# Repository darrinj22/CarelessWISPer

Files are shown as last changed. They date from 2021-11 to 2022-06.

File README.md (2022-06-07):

# CarelessWISPer 
Wireless Electronic Shopping Label | 
NCSU Senior Capstone Project 2021

## Introduction
CarelessWISPer, named after the famous (infamous?) George Michael song, is an Electronic Shopping Label System. Engineered
to act as an RFID area reader for consumer products, item tracking, and further applications. Using an ePaper Display, and ESP32 microcontroller, and an RFID module, this product has the capability of giving detailed item descriptions of each product on a shelf. 

## How to Browse

- This github repository is split into 3 main sections: Code, Tutorials, and Fabrication Files
- Within the code section, all of the code that was used to make this project work can be found. Note that this requires the installation of either the Arduino IDE (if you use all the code packed into one .ino file), or the Platform.io extension in Visual Studio to utilize the better and more structured codebase.
- The tutorial section contains descriptions on setting up the database using XAMPP, as well as establishing connection between the ESP32 and ePaper Display. 
- The fabrication section will contain all of the gerber files necessary to fabricate the PCB and needed parts for the project. 

## Installation
To use these code files to implement this system. Read the files contained within the Tutorials section. 

## Contact
Contact darrinjhansen@gmail.com for any questions.

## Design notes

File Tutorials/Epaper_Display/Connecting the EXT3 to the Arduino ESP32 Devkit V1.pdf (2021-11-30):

# Connecting the EXT3 to the ESP32 Devkit V1 with Arduino

# Scope

This configuration has been tested successfully against

ESP32 Devkit V1 (https://embeddedcomputing.weebly.com/espressif-platform.html) for the screens up to 2.66"

This configuration may also suit other boards with the Arduino form-factor, with the size of the screen adapted to the available SRAM of the MCU.

# Software

On the main sketch, set the board to boardESP32,

corresponding to the pins defined in the

### hV_Configuration.h file of the

ePaper_EXT3_Basic_Library (link 1, (https://github.com/PervasiveDisplays/PDLS_EXT3_Basic) link 2). (https://github.com/rei-vilo/PDLS_EXT3_Basic)

# Notes

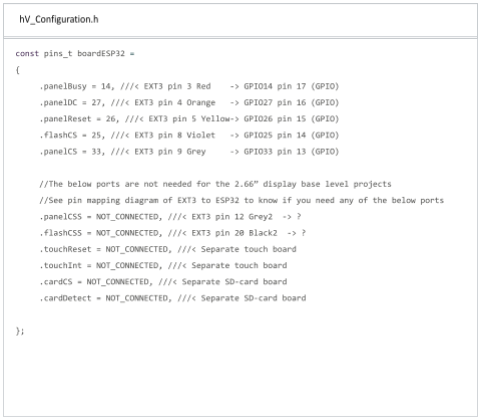
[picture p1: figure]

There are multiple releases of the ESP32 (https://embeddedcomputing.weebly.com/espressif-platform.html) with slight incompatibilities. In this we are using the ESP32 Devkit V1. Setup the ESP32 library in Arduino IDE by following the steps found here. (https://randomnerdtutorials.com/installing-the-esp32-board-in-arduino-ide-windows-instructions/)

After downloading the code from the above-mentioned github repository, there are a couple of things that need to be completed before flashing the project to ESP32. First, open up hV.Configuration, and declare the board that will be used, in our case, boardESP32. We have configured this specific pin mapping (remember, the pin number reflects the GPIO pin and not necessarily the physical pin number) so that it is compatible with the example projects in the ePaper_EXT_3_Basic_Library. If the GPIO pins we have mapped conflict with your project specifications, adjust accordingly (See Figure 3 Hardware). Next, whatever example.ino file you decide to use from ePaper_EXT3_Basic_Library, you will need to declare your board in the example.ino file as seen in the Sketch.ino image above. Make sure all other declarations are commented out except for the screen that you will be using. For our 2.66” display, we have selected the declaration with eScreen_EPD_EXT3_266 input. Finally, connect the EXT3 board to ESP32 (See Figure 2 Hardware), flash the selected example.ino project onto your ESP32 from Arduino IDE and make sure the image showing on your display matches the example description.

Issue: Some ESP32 will not flash in the Arduino environment. This happened in this example. The work around is to install a 10uf electrolytic capacitor to make the ESP32 automatically go into boot/flash mode (See Figure 1 in Hardware). After configuring the circuit either by soldering the capacitor to the board, or using a breadboard as seen in the figure below, ESP32 should be able to successfully flash code through Arduino IDE.

# Hardware

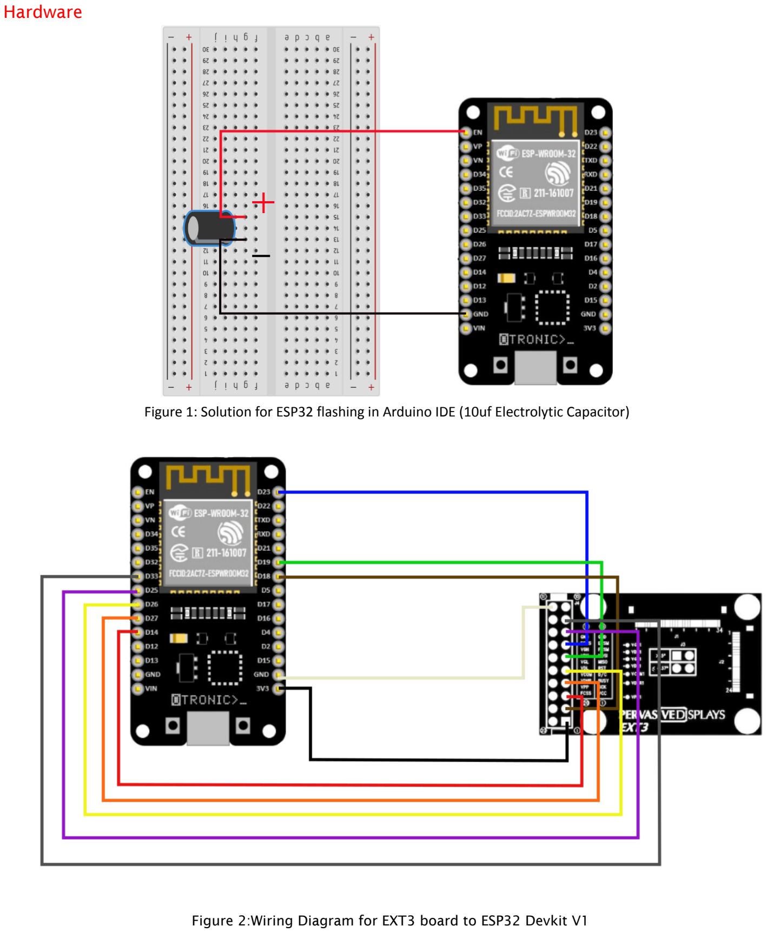
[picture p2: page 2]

## Figure 1: Solution for ESP32 flashing in Arduino IDE (10uf Electrolytic Capacitor)

## Figure 2:Wiring Diagram for EXT3 board to ESP32 Devkit V1

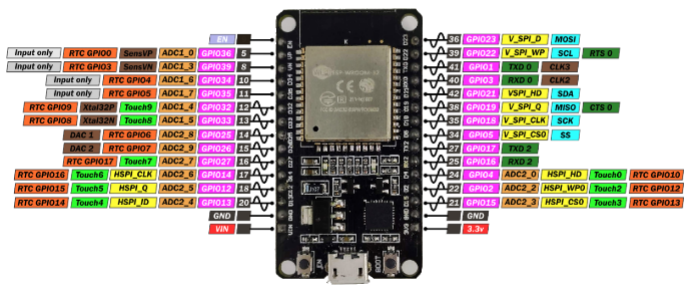
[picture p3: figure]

## Figure 3: ESP32 Devkit V1 Pinout

# Options

Large screens 9.7" and 12.2" require panelCSS to be defined and connected.

If the second memory is populated on the EXT3 board, lashCSS needs to be defined and connected. The library will keep lashCSS HIGH to avoid any interferences with the other

devices connected to the SPI bus.

ESP32 Image: https://www.otronic.nl/a-59613972/esp32/esp32-wroom-4mb-devkit-v1-board-met-wifi-bluetooth-en-dual-core-processor/ , Otronic

Pervasive Display EXT3 Image:https://embeddedcomputing.weebly.com/connecting-the-e-paper-epd-extension-kit-gen-3.html. , REI VILO

ESP32 Pinout Image: https://www.mischianti.org/wp-content/uploads/2020/11/ESP32-DOIT-DEV-KIT-v1-pinout-mischianti.png , RENZO MISCHIANTI (https://www.mischianti.org/author/reef/)

Created 10/12/2021 W. Shepherd Pitts, PhD, NCSU
Modified 10/12/2021 Joe Harrison, NCSU

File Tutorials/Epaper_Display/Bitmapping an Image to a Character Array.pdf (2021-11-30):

## Bitmapping a BMP/PNG Image to a Character Array and Displaying the Image on Pervasive Display's - 2.66" E ink Display - Aurora -25(V430)

## Scope

This configuration has been tested successfully against

ESP32 Devkit V1 (https://embeddedcomputing.weebly.com/espressif-platform.html) for the screens up to 2.66”

This configuration may also suit other boards with the Arduino form-factor, with the size of the screen adapted to the available SRAM of the MCU.

## Software

If not already done, follow the instructions ***HERE*** (https://docs.google.com/document/u/1/d/1n4Jl7uKD6odnbmRgLsNShRXBoZbzR4CFlCR1YncSQME/edit) to get the correct setup required to display an image on the 2.66” E ink display from Pervasive Display.

## Notes

After having completed the setup from the linked document in the Software section, you should be able to display the images found in the example.ino files in Arduino IDE. Next, we will now configure our project to be able to display custom images through bit mapping images to C/C++ character arrays.

Step 1:
Download the github repository located here. After downloading the files, open up the EPD_sub_5_inch.ino file. Start off by declaring your board much like in the guide for connecting the EXT3 board. Also you will need to correctly declare valid pins for your board. (See below) Then run the program to make sure that the project is flashing correctly to ESP32.
The program should display an image for around 5 seconds, and then display a second image.

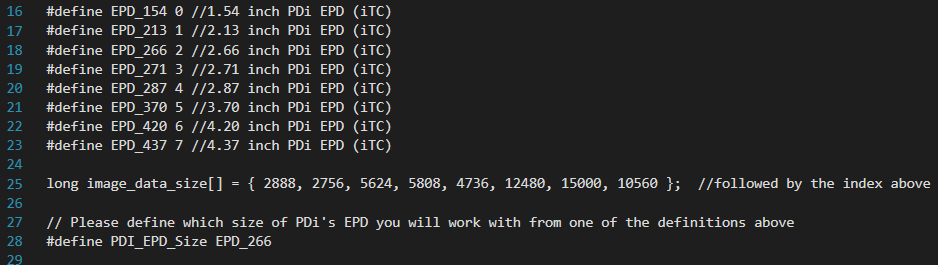
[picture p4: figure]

For the code below, you will have to make sure that the pins are aligned correctly with the configuration that you are using for your specific project.

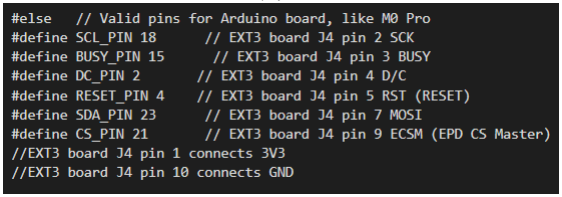
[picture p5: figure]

Next, locate this chunk of code:

Step 2:
Directly underneath this code, delete/comment out the following lines. #include "image_data\2.66\image_266_296x152_BWR.c"
#define BWR_blackBuffer | (uint8_t *) & image_266_296x152_BWR_blackBuffer

#define BWR_redBuffer | (uint8_t *) & image_266_296x152_BWR_redBuffer

So now your code should look like this:

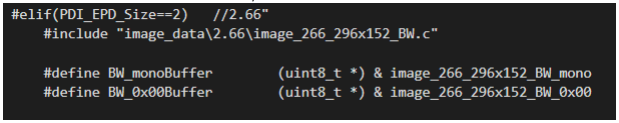
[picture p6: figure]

Step 3:
Next, open up the file in the directory above, image_266_296x152_BW.c This is the file that contains the arrays for whichever image you are going to be displaying on your screen. First, delete the code that sends the second image:

// Send 2nd image data for black, white and red colors
sendIndexData( 0x10, BWR_blackBuffer, image_data_size[PDI_EPD_Size] ); //First frame: black frame where 1=black and 0=white or color pixel sendIndexData( 0x13, BWR_redBuffer, image_data_size[PDI_EPD_Size] ); //Second frame: color frame where 1=color and 0=white or black pixel sendIndexData( 0x12, &register_data[0], 1 ); //Display Refresh
while( digitalRead( BUSY_PIN ) != HIGH );

This will make it easier for debugging because you will only be focused on being able to Send one image to your board. Once you can correctly send a desired image to your board, you can go back and add the code to send multiple images to the board.

Step 4:
Within the image_266_296x152_BW.c file, delete all the characters within the image_266_296x152_BW_mono array, but do not delete the array declaration, because once we correctly bitmap an image, we will paste the converted image into the array declaration. Now, we will take a black and white image of your choice to be updated on the display. I used the image found here. (https://raw.githubusercontent.com/PervasiveDisplays/ePaper_EXT3_DrivingCode/main/EPD_sub_5_inch/images/2.66/266_296x152_BW.bmp) Since we already have the array for this image, we will open this image up in an editor (Photoshop,Gimp,etc.) and change the image to your liking. Then, rotate the image within the editor so that it has this orientation

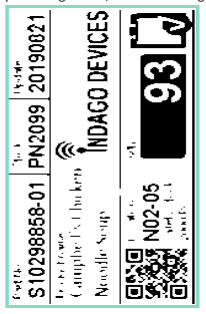
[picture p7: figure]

Save the image as a .bmp or .png file. Depending on the photo editor that you are using, one of these types of files will be needed for the next step. While doing the next step, If the .bmp does not work, try it with the .png instead, and vice versa.

Step 5:
Open up the website found here. (https://javl.github.io/image2cpp/) Select the image that you edited in the previous step and upload it to the application. Within the image settings, make sure you have the canvas size set appropriately(for the 2.66” display, 152x296). Also you will most likely need to invert the image colors. You should now see your image in the preview like this

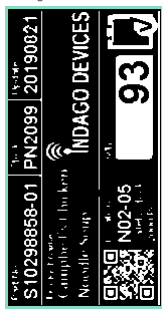
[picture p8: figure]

Next, go the output portion of the application and make sure that output format is set to Arduino Code, and the Draw mode is set To Horizontal - 1 bit per pixel. Now generate the code. Take the array that was generated and paste it into the array that we talked about in step 4.

Step 6:
After saving the array, now run the EPD_sub_5_inch.ino program and the display should be outputting the image that you created within your editor.

## Desired Outcome

Here, (https://drive.google.com/file/d/11dbviFQ2u1dpbYEQ8GaudZTZPbHVXqvW/view?usp=sharing) you will see a basic program that runs through 4 images.

To get over the air flashing of your ESP32, follow the guide found here. (https://lastminuteengineers.com/esp32-ota-web-updater-arduino-ide/)

Lastly, here are some useful links concerning the ESP32/Epaper display. (https://docs.google.com/document/d/1-DGhHi2krR2uHqgw9-P19peYgrpZNnmpY0OJPN4OhO0/edit)

## Options

Large screens 9.7" and 12.2" require panelCSS to be defined and connected.

If the second memory is populated on the EXT3 board, lashCSS needs to be defined and

connected. The library will keep lashCSS HIGH to avoid any interferences with the other

devices connected to the SPI bus.

Created 10/12/2021 Joe Harrison, NCSU

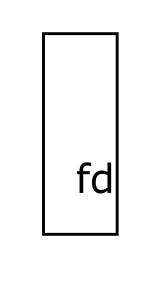
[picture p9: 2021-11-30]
bitmap1.png

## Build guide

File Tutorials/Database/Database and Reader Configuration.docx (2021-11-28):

Database and Reader Configuration

The goal of this document is to detail the storage of data collected from the reader. For the purposes of this project, only the EPC codes were scanned and captured, but all data from tags such as the wisp could be collected and stored in a similar fashion. The flow chart below describes the process:

Reader gets tag info → ESP32 collects the data → HTTP Request to Web Server → PHP Script → MySQL

We’re going to assume we already have the data that we need to input and begin the setup of the actual database.

Database Configuration

1. Download XAMPP. https://www.apachefriends.org/download.html

XAMPP is an open-source web server stack that stands for Apache HTTP server, MariaDB (MySQL) database, PHP, and Perl. We are going to use XAMPP as a local server to host our information.

2. Once downloaded, open XAMPP and start both the Apache and MySQL Modules, the other three aren’t used.
3. Open the Shell on the XAMPP control panel.
4. Login once using the root username and password by using the following in the shell:
  a. mysql.exe -u root -p
  b. You will then be prompted to enter a password, the password for the root account is: “your-root-password”
5. Now we are going to create a user account that we will use to access the database. The username is CarelessWISPer and the password is shep_123. These can be set to anything when first created. Type the following in the shell:
  a. CREATE USER ‘CarelessWISPer’@’localhost’ IDENTIFIED BY ‘shep_123’;

GRANT ALL PRIVILEGES ON *.* TO ‘CarelessWISPer’@’localhost’ WITH GRANT OPTION;

FLUSH PRIVILEGES;

6. To login to our newly created account, quit the MariaDB editor and reopen, then type:
  a. Mysql.exe -u CarelessWISPer -p
  b. Use ‘shep_123’ as the password.
7. Since we will be storing the epc values from the tags, we will create a database and table to store them. First, create a database called db_epc by entering the following into the shell:
  a. CREATE DATABASE db_epc CHARACTER SET = ‘utf8’ COLLATE=’utf8_general_ci’;
8. Now, create a table within the database that will actually store the information. First set which database we will be working in:
  a. USE db_epc;
9. Then, create the table named epc_vals ( the name doesn’t matter as long as everything is consistent across the ESP32 code, PHP script and MySQL Server).

CREATE TABLE epc_vals(

tag_id INT UNSIGNED NOT NULL AUTO_INCREMENT,

product_name VARCHAR(40),

tag_epc VARCHAR(36),

last_edited TIMESTAMP(6) NOT NULL DEFAULT CURRENT_TIMESTAMP(6) ON UPDATE CURRENT_TIMESTAMP(6),

tag_state VARCHAR(30),

entry_date DATETIME(6),

PRIMARY KEY (tag_id));

10. Now that we have a place to store our values, we can look into actually inserting them by writing a php script. Open a text editor and paste the following code, there should also be a php file included in the folder where this document was found that contains this code.

<?php

if(isset($_GET["epc"])) {

$epc = $_GET["epc"];

$servername = "localhost";

$username = "CarelessWISPer";

$password = "shep_123";

$dbname = "db_epc";

$timeout = "20";

// Create connection

$conn = new mysqli($servername, $username, $password, $dbname);

// Check connection

if ($conn->connect_error) {

die("Connection failed: " . $conn->connect_error);

}

$sql = "CALL insert_data($epc,$timeout)";

if ($conn->query($sql) === TRUE) {

echo "New record created successfully";

} else {

echo "Error: " . $sql . " => " . $conn->error;

}

$conn->close();

} else {

echo "epc is not set";

}

?>

Save the code from above as a .php file and make sure that it is in the following directory:

a. C:\xampp\htdocs
11. One thing to note is that in the php file, there is a line that reads:
  a. $sql = “CALL insert_data($epc,$timeout)”;

This is a call to a stored procedure in the database, you will need to make this function in order to make sure this works properly, to do so, paste the following code into the MySQL shell:

DELIMITER //

CREATE PROCEDURE insert_data(parameter_tag_epc VARCHAR(36), parameter_timeout INTEGER)

MODIFIES SQL DATA

BEGIN

INSERT INTO epc_vals (tag_epc,entry_date,tag_state) VALUES (parameter_tag_epc,NOW(),'Recent Batch');

DELETE FROM epc_vals WHERE entry_date < NOW() - INTERVAL parameter_timeout MINUTE;

UPDATE epc_vals SET tag_state = 'Old Batch' WHERE entry_date < NOW() - INTERVAL 70 SECOND;

UPDATE epc_vals SET product_name = 'CHEEZIT' WHERE LEFT(tag_epc,11) = '22600295125';

UPDATE epc_vals SET product_name = 'MT DEW' WHERE LEFT(tag_epc,11) = '16026516616';

CREATE OR REPLACE TABLE product_info SELECT product_name, tag_epc,entry_date, COUNT(*) times_item_was_seen FROM epc_vals GROUP BY tag_epc ORDER BY entry_date DESC;

END;//

DELIMITER ;

A few things to note, specifically with the lines marked yellow. These are only used as a way to distinguish between our specific tags and organize the data we had, they are not necessary to the functionality of the database.

12. Then, create an Arduino Sketch and place the following code into three separate files. Make sure to change the wifi and server settings to your appropriate settings.

Main Code:

/*

Epaper Display Scan for Gen2 EPC Values and Update Database

Authors: DJ Hansen, Joe Harrison, Jon Mark Long, Daniel Higgins

Date: November 29th, 2021

About: Electronic Wireless Shopping Label System code including Gen 2 Reader, MySQL Database Connection, and

Wireless Updating of EPaper Display

*/

/*

*********************************************************************************************************************************

* Preproccesor Directives, MACROS, and header files *

*********************************************************************************************************************************

*/

// processor predirectives and MACROS

#define use_soft_serial 0 // predirective to control whether using software or hardware serial port, if set to 1, then switch on M6E needs to be set to SW

#define DEBUG 0 // 0 : no messages 1 : request sending and receiving

#define EPC_COUNT 20 // how many tags are expected in the area, can reasonably go up to around 100

#define NANOREGION REGION_NORTHAMERICA //which region the reader operates in, check https://github.com/sparkfun/Simultaneous_RFID_Tag_Reader for other regions

#define ALWAYS 1

// Reader header files

#include "SparkFun_UHF_RFID_Reader.h" //Library for controlling the M6E Nano module

#if use_soft_serial

#include <SoftwareSerial.h> //Used for transmitting to the device

SoftwareSerial softSerial(2, 3); //RX, TX

#else

#define NanoSerial Serial // define the serial port to use (E.g. softSerial, Serial1 etc)

#endif

// Database header files

#include <WiFi.h>

#include <HTTPClient.h>

// ePaper header files

#include <WiFiClient.h>

#include <WebServer.h>

#include <ESPmDNS.h>

#include <Update.h>

#include <SPI.h>

/****************************************************************************************************************************

* Global Variables and Objects needed for Reader and Database Functionality *

****************************************************************************************************************************

*/

uint8_t EPC_recv[EPC_COUNT][12]; //stores unique tag values in a session

const unsigned long time_pd_wait = 60000; // how long we should wait in between scan sessions (ms)

const unsigned long time_pd_scan = 30000; // scan duration (ms)

unsigned long prev_time = 0; // timer wait update

unsigned long prev_scan_time = 0; // timer scan update

bool onetime = true; // one time flag

bool firstTime = true; // one time flag

unsigned long scan_time = 0; // used to store millis()

const char WIFI_SSID[] = "ncsu"; // wifi network name

const char WIFI_PASSWORD[] = ""; // wifi password

String HOST_NAME = "http://10.155.25.216:80"; // PC's IP address, use port 80

String PATH_NAME = "/insert_epc.php"; // php file placed in C:\xampp\htdocs

String queryString; // query to send to database

String final_epc[EPC_COUNT]; // string epc values

const unsigned long update_db = 30000; //database update time (ms)

unsigned long prev_time_db = 0; // timer update

uint8_t first_flag = 0; // one time flag

int httpCode; // stores code from http connection attempt

String payload; //

// Object Instances

RFID nano; //Create instance for reader

HTTPClient http; //Create instance for http connection

/*

*

* **********************************************************************************************************************

* Everything from this point until line 365 is used for Updating and Flashing an image onto the Epaper Display *

* **********************************************************************************************************************

*/

bool add_image_done = false;

const char* host = "esp32";

const char* ssid = "ncsu";

const char* password = "";

#define EPD_154 0 //1.54 inch PDi EPD (iTC)

#define EPD_213 1 //2.13 inch PDi EPD (iTC)

#define EPD_266 2 //2.66 inch PDi EPD (iTC)

#define EPD_271 3 //2.71 inch PDi EPD (iTC)

#define EPD_287 4 //2.87 inch PDi EPD (iTC)

#define EPD_370 5 //3.70 inch PDi EPD (iTC)

#define EPD_420 6 //4.20 inch PDi EPD (iTC)

#define EPD_437 7 //4.37 inch PDi EPD (iTC)

long image_data_size[] = { 2888, 2756, 5624, 5808, 4736, 12480, 15000, 10560 }; //followed by the index above

#define PDI_EPD_Size EPD_266

#if (PDI_EPD_Size >= 5) //3.70", 4.20", 4.37"

uint8_t register_data[] = { 0x00, 0x0e, 0x19, 0x02, 0x0f, 0x89 }; //0x00, soft-reset, temperature, active temp., PSR0, PSR1

#else //other small sizes

uint8_t register_data[] = { 0x00, 0x0e, 0x19, 0x02, 0xcf, 0x8d };

#endif

#if(PDI_EPD_Size==2)//2.66"

#include "image_266_296x152_BW.c"

#define BW_monoBuffer (uint8_t *) & image_266_296x152_BW_monoTest

#define BW_monoBuffer1 (uint8_t *) & image_266_296x152_BW_mono1

#define BW_monoBuffer2 (uint8_t *) & image_266_296x152_BW_mono2

#define BW_monoBuffer3 (uint8_t *) & image_266_296x152_BW_mono3

#define BW_monoBuffer4 (uint8_t *) & image_266_296x152_BW_mono4

#define BW_0x00Buffer (uint8_t *) & image_266_296x152_BW_0x00

#elif(PDI_EPD_Size==3) //2.71"

#include "image_data\2.71\image_271_264x176_BW.c"

#include "image_data\2.71\image_271_264x176_BWR.c"

#define BW_monoBuffer (uint8_t *) & image_271_264x176_BW_mono

#define BW_0x00Buffer (uint8_t *) & image_271_264x176_BW_0x00

#define BWR_blackBuffer (uint8_t *) & image_271_264x176_BWR_blackBuffer

#define BWR_redBuffer (uint8_t *) & image_271_264x176_BWR_redBuffer

#endif

#if defined(ENERGIA) // Valid pins for LaunchPad on Energia

#define SCL_PIN 7 // EXT3 board J4 pin 2 SCK

#define BUSY_PIN 11 // EXT3 board J4 pin 3 BUSY

#define DC_PIN 12 // EXT3 board J4 pin 4 D/C

#define RESET_PIN 13 // EXT3 board J4 pin 5 RST (RESET)

#define SDA_PIN 15 // EXT3 board J4 pin 7 MOSI

#define CS_PIN 19 // EXT3 board J4 pin 9 ECSM (EPD CS Master)

// SPI protocl setup

void sendIndexData( uint8_t index, const uint8_t *data, uint32_t len ) {

SPI.begin ();

SPI.setDataMode(SPI_MODE3);

SPI.setClockDivider(SPI_CLOCK_DIV32);

SPI.setBitOrder(MSBFIRST);

digitalWrite( DC_PIN, LOW ); //DC Low

digitalWrite( CS_PIN, LOW ); //CS Low

delayMicroseconds(500);

SPI.transfer( index );

delayMicroseconds(500);

digitalWrite( CS_PIN, HIGH ); //CS High

digitalWrite( DC_PIN, HIGH ); //DC High

digitalWrite( CS_PIN, LOW ); //CS Low

delayMicroseconds(500);

for ( int i = 0; i < len; i++ ) SPI.transfer( data[ i ] );

delayMicroseconds(500);

digitalWrite( CS_PIN, HIGH ); //CS High

}

#else // Valid pins for Arduino board, like M0 Pro

#define SCL_PIN 18 // EXT3 board J4 pin 2 SCK

#define BUSY_PIN 15 // EXT3 board J4 pin 3 BUSY

#define DC_PIN 2 // EXT3 board J4 pin 4 D/C

#define RESET_PIN 4 // EXT3 board J4 pin 5 RST (RESET)

#define SDA_PIN 23 // EXT3 board J4 pin 7 MOSI

#define CS_PIN 21 // EXT3 board J4 pin 9 ECSM (EPD CS Master)

// Software SPI setup

void softwareSpi( uint8_t data ) {

for ( int i = 0; i < 8; i++ ) {

if ((( data >> (7 - i) ) & 0x01 ) == 1 ) digitalWrite( SDA_PIN, HIGH );

else digitalWrite( SDA_PIN, LOW );

digitalWrite( SCL_PIN, HIGH );

digitalWrite( SCL_PIN, LOW );

}

}

// Software SPI protocl setup

void sendIndexData( uint8_t index, const uint8_t *data, uint32_t len ) {

digitalWrite( DC_PIN, LOW ); //DC Low

digitalWrite( CS_PIN, LOW ); //CS Low

softwareSpi( index );

digitalWrite( CS_PIN, HIGH ); //CS High

digitalWrite( DC_PIN, HIGH ); //DC High

digitalWrite( CS_PIN, LOW ); //CS High

for ( int i = 0; i < len; i++ ) softwareSpi( data[ i ] );

digitalWrite( CS_PIN, HIGH ); //CS High

}

#endif

//variabls for blinking an LED with Millis

const int led = 2; // ESP32 Pin to which onboard LED is connected

unsigned long previousMillis = 0; // will store last time LED was updated

const long interval = 1000; // interval at which to blink (milliseconds)

int ledState = LOW; // ledState used to set the LED

WebServer server(80);

/*

* Login page

*/

const char* loginIndex =

"<form name='loginForm'>"

"<table width='20%' bgcolor='A09F9F' align='center'>"

"<tr>"

"<td colspan=2>"

"<center><font size=4><b>ESP32 Login Page</b></font></center>"

"<br>"

"</td>"

"<br>"

"<br>"

"</tr>"

"<tr>"

"<td>Username:</td>"

"<td><input type='text' size=25 name='userid'><br></td>"

"</tr>"

"<br>"

"<br>"

"<tr>"

"<td>Password:</td>"

"<td><input type='Password' size=25 name='pwd'><br></td>"

"<br>"

"<br>"

"</tr>"

"<tr>"

"<td><input type='submit' onclick='check(this.form)' value='Login'></td>"

"</tr>"

"</table>"

"</form>"

"<script>"

"function check(form)"

"{"

"if(form.userid.value=='admin' && form.pwd.value=='admin')"

"{"

"window.open('/serverIndex')"

"}"

"else"

"{"

" alert('Error Password or Username')/*displays error message*/"

"}"

"}"

"</script>";

/*

* Server Index Page

*/

const char* serverIndex =

"<script src='https://ajax.googleapis.com/ajax/libs/jquery/3.2.1/jquery.min.js'></script>"

"<form method='POST' action='#' enctype='multipart/form-data' id='upload_form'>"

"<input type='file' name='update'>"

"<input type='submit' value='Update'>"

"</form>"

"<div id='prg'>progress: 0%</div>"

"<script>"

"$('form').submit(function(e){"

"e.preventDefault();"

"var form = $('#upload_form')[0];"

"var data = new FormData(form);"

" $.ajax({"

"url: '/update',"

"type: 'POST',"

"data: data,"

"contentType: false,"

"processData:false,"

"xhr: function() {"

"var xhr = new window.XMLHttpRequest();"

"xhr.upload.addEventListener('progress', function(evt) {"

"if (evt.lengthComputable) {"

"var per = evt.loaded / evt.total;"

"$('#prg').html('progress: ' + Math.round(per*100) + '%');"

"}"

"}, false);"

"return xhr;"

"},"

"success:function(d, s) {"

"console.log('success!')"

"},"

"error: function (a, b, c) {"

"}"

"});"

"});"

"</script>";

void add_image(void){

pinMode( SCL_PIN, OUTPUT );

pinMode( SDA_PIN, OUTPUT );

pinMode( CS_PIN, OUTPUT );

pinMode( DC_PIN, OUTPUT );

pinMode( RESET_PIN, OUTPUT );

pinMode( BUSY_PIN, INPUT ); //All Pins 0

delay( 5 );

digitalWrite( RESET_PIN, HIGH ); //RES# = 1

delay( 5 );

digitalWrite( RESET_PIN, LOW );

delay( 10 );

digitalWrite( RESET_PIN, HIGH );

delay( 5 );

digitalWrite( CS_PIN, HIGH ); //CS# = 1

sendIndexData( 0x00, &register_data[1], 1 ); //Soft-reset

while( digitalRead( BUSY_PIN ) != HIGH );

sendIndexData( 0xe5, &register_data[2], 1 ); //Input Temperature: 25C

sendIndexData( 0xe0, &register_data[3], 1 ); //Active Temperature

sendIndexData( 0x00, &register_data[4], 2 ); //PSR

// Send 1st image data for black and white colors

sendIndexData( 0x10, BW_monoBuffer1, image_data_size[PDI_EPD_Size] ); //First frame: black frame where 1=black and 0=white pixel

sendIndexData( 0x13, BW_0x00Buffer, image_data_size[PDI_EPD_Size] ); //Second frame: all 0x00

sendIndexData( 0x04, &register_data[0], 1 ); //Power on

while( digitalRead( BUSY_PIN ) != HIGH );

sendIndexData( 0x12, &register_data[0], 1 ); //Display Refresh

while( digitalRead( BUSY_PIN ) != HIGH );

delay( 5000 );

// Send 2nd image data for black and white colors

sendIndexData( 0x10, BW_monoBuffer2, image_data_size[PDI_EPD_Size] ); //First frame: black frame where 1=black and 0=white pixel

sendIndexData( 0x13, BW_0x00Buffer, image_data_size[PDI_EPD_Size] ); //Second frame: all 0x00

sendIndexData( 0x04, &register_data[0], 1 ); //Power on

while( digitalRead( BUSY_PIN ) != HIGH );

sendIndexData( 0x12, &register_data[0], 1 ); //Display Refresh

while( digitalRead( BUSY_PIN ) != HIGH );

delay( 5000 );

// Send 3rd image data for black and white colors

sendIndexData( 0x10, BW_monoBuffer3, image_data_size[PDI_EPD_Size] ); //First frame: black frame where 1=black and 0=white pixel

sendIndexData( 0x13, BW_0x00Buffer, image_data_size[PDI_EPD_Size] ); //Second frame: all 0x00

sendIndexData( 0x04, &register_data[0], 1 ); //Power on

while( digitalRead( BUSY_PIN ) != HIGH );

sendIndexData( 0x12, &register_data[0], 1 ); //Display Refresh

while( digitalRead( BUSY_PIN ) != HIGH );

delay( 5000 );

//Turn-off DC/DC

sendIndexData( 0x02, &register_data[0], 1 ); //Turn off DC/DC

while( digitalRead( BUSY_PIN ) != HIGH );

digitalWrite( DC_PIN, LOW );

digitalWrite( CS_PIN, LOW );

digitalWrite( SDA_PIN, LOW );

digitalWrite( SCL_PIN, LOW );

digitalWrite( BUSY_PIN, LOW );

delay( 150 );

digitalWrite( RESET_PIN, LOW );

}

// End Joe stuff

/*

* ******************************************************************************************************************************

* Function: Setup

* Author: DJ Hansen, Joe Harrison, Jon Mark Long, Daniel Higgins

* Date: 11/29/2021

* About:

* Runs once before going into the Always loop.

* Sets up WiFi, Server, and Serial Connections

* ******************************************************************************************************************************

*/

void setup()

{

Serial.begin(115200);

// Connect to WiFi network

WiFi.begin(ssid, password);

Serial.println("");

// Wait for connection

while (WiFi.status() != WL_CONNECTED) {

delay(500);

Serial.print(".");

}

Serial.println("");

Serial.print("Connected to ");

Serial.println(ssid);

Serial.print("IP address: ");

Serial.println(WiFi.localIP());

/******************************************************************************************************************************/

// Begin Server Connection Setup for EPaper Display

/*use mdns for host name resolution*/

if (!MDNS.begin(host)) { //http://esp32.local

Serial.println("Error setting up MDNS responder!");

while (1) {

delay(1000);

}

}

Serial.println("mDNS responder started");

/*return index page which is stored in serverIndex */

server.on("/", HTTP_GET, []() {

server.sendHeader("Connection", "close");

server.send(200, "text/html", loginIndex);

});

server.on("/serverIndex", HTTP_GET, []() {

server.sendHeader("Connection", "close");

server.send(200, "text/html", serverIndex);

});

/*handling uploading firmware file */

server.on("/update", HTTP_POST, []() {

server.sendHeader("Connection", "close");

server.send(200, "text/plain", (Update.hasError()) ? "FAIL" : "OK");

ESP.restart();

}, []() {

HTTPUpload& upload = server.upload();

if (upload.status == UPLOAD_FILE_START) {

Serial.printf("Update: %s\n", upload.filename.c_str());

if (!Update.begin(UPDATE_SIZE_UNKNOWN)) { //start with max available size

Update.printError(Serial);

}

} else if (upload.status == UPLOAD_FILE_WRITE) {

/* flashing firmware to ESP*/

if (Update.write(upload.buf, upload.currentSize) != upload.currentSize) {

Update.printError(Serial);

}

} else if (upload.status == UPLOAD_FILE_END) {

if (Update.end(true)) { //true to set the size to the current progress

Serial.printf("Update Success: %u\nRebooting...\n", upload.totalSize);

} else {

Update.printError(Serial);

}

}

});

server.begin();

// End Server Connection Setup for EPaper Display

/******************************************************************************************************************************/

// Begin Reader Setup

init_array(); // initializes storage values of EPC to all 0

Serial.begin(115200); // defined elsewhere, can probably remove

while (!Serial); //Wait for the serial port to come online

Serial.println(F("Ready to Begin Program")); //If this prints, then no wiring issues found

if (DEBUG) nano.enableDebugging(Serial);

// SetupNano establishes connection between ESP32 and M6E Nano Reader

if (setupNano(38400) == false) //Configure nano to run at 38400bps

{

Serial.println(F("Module failed to respond. Please check wiring."));

while (1); //Freeze!

}

nano.setRegion(NANOREGION); //Set to the right region

nano.setReadPower(500); //5.00 dBm. Higher values may caues USB port to brown out

//Max Read TX Power is 27.00 dBm and may cause temperature-limit throttling

// End Reader Setup

// Database setup

connect_to_wifi();

/**********************************************************************************************************************************/

}

/*

* **********************************************************************************************************************************************

* Function: loop

* Author: DJ Hansen and Joe Harrison

* Date: 11/29/2021

* From: North Carolina State University

* About:

* This loop runs continuously, checking first to make sure ePaper display is properly setup,

* Then goes into loop of scanning for time_pd_scan and then waiting for time_pd_wait

* Any Use of Serial.println is used for debugging purposes only and does not affect the outcome of the program

*

*

* **********************************************************************************************************************************************

*/

void loop()

{

unsigned long curr_time = millis(); // gets current run time

/*************************************************************************************************************************************************/

// Begin Epaper Section of Loop

server.handleClient();

delay(5);

if(!add_image_done){

add_image();

add_image_done = true;

}

// End Epaper Section of loop

/*************************************************************************************************************************************************/

// Begin Reader and Database Loop

if(((curr_time - prev_time) >= time_pd_wait) || onetime){ // This checks for two things: either we are going into this loop for the first time,

onetime = false; // or we have waited the designated amount of time.

clear_arrays();

nano.startReading(); //Begin scanning for tags

Serial.println(F("Done waiting"));

prev_scan_time = millis();

scan_time = millis();

scan_time += 1;

while(scan_time - prev_scan_time < time_pd_scan){ // Stay in this loop until we have been in it for time_pd_scan ms

scan_time = millis();

if (nano.check() == true) //Check to see if any new data has come in from module

{

byte responseType = nano.parseResponse(); //Break response into tag ID, RSSI, frequency, and timestamp

if (responseType == RESPONSE_IS_KEEPALIVE) // Haven't found anything yet......

{

Serial.println(F("Scanning"));

}

else if (responseType == RESPONSE_IS_TAGFOUND) // Great! We found a Tag!

{

//If we have a full record we can pull out the fun bits

int rssi = nano.getTagRSSI(); //Get the RSSI for this tag read

long freq = nano.getTagFreq(); //Get the frequency this tag was detected at

long timeStamp = nano.getTagTimestamp(); //Get the time this was read, (ms) since last keep-alive message

byte tagEPCBytes = nano.getTagEPCBytes(); //Get the number of bytes of EPC from response

if(check_array(nano.msg)){ // Check to see if we have already found this tag in this session, don't do anything if we have

}else{

add_array(nano.msg); // If we haven't then store it

//Print EPC bytes, this is a subsection of bytes from the response/msg array

Serial.print(F(" epc[")); // This code is just used to print it to serial output

for (byte x = 0 ; x < tagEPCBytes ; x++)

{

if (nano.msg[31 + x] < 0x10) Serial.print(F("0"));

Serial.print(nano.msg[31 + x], HEX);

Serial.print(F(" "));

}

Serial.print(F("]"));

Serial.println();

}

}

else if (responseType == ERROR_CORRUPT_RESPONSE) // Bad CRC

{

Serial.println("Bad CRC");

}

else

{

//Unknown response

Serial.print("Unknown error");

}

}

}

firstTime = false; // Shut Everything down and begin storing found tags in database

nano.stopReading();

Serial.println(F("Done scanning"));

delay(500);

database();

prev_time = curr_time;

}

// End Reader and Database Loop

/*********************************************************************************************************************************************/

}

/************************************************************************************************************************************************

* Function: setupNano

* Author: Nathan Seidle @ SparkFun Electronics

* Date: October 3rd, 2016

* From: https://github.com/sparkfun/Simultaneous_RFID_Tag_Reader

* About: Gracefully handles a reader that is already configured and already reading continuously

* Because Stream does not have a .begin() we have to do this outside the library

*

**********************************************************************************************************************************************/

boolean setupNano(long baudRate)

{

nano.begin(NanoSerial); //Tell the library to communicate over serial port

//Test to see if we are already connected to a module

//This would be the case if the Arduino has been reprogrammed and the module has stayed powered

NanoSerial.begin(baudRate); //For this test, assume module is already at our desired baud rate

while(!NanoSerial); //Wait for port to open

//About 200ms from power on the module will send its firmware version at 115200. We need to ignore this.

while(NanoSerial.available()) NanoSerial.read();

nano.getVersion();

if (nano.msg[0] == ERROR_WRONG_OPCODE_RESPONSE)

{ //This happens if the baud rate is correct but the module is doing a ccontinuous read

nano.stopReading();

Serial.println(F("Module cont. reading. Asking it to stop..."));

delay(1500);

}

else if (nano.msg[0] != ALL_GOOD)

{ //The module did not respond so assume it's just been powered on and communicating at 115200bps

NanoSerial.begin(115200); //Start software serial at 115200

nano.setBaud(baudRate); //Tell the module to go to the chosen baud rate. Ignore the response msg

NanoSerial.begin(baudRate); //Start the serial port, this time at user's chosen baud rate

nano.getVersion(); //Test the connection

if (nano.msg[0] != ALL_GOOD) return (false); //Something is not right

}

//The M6E has these settings no matter what

nano.setTagProtocol(); //Set protocol to GEN2

nano.setAntennaPort(); //Set TX/RX antenna ports to 1

return (true); //We are ready to rock

}

/************************************************************************************************************************************************

* Function: init_array

* Author: DJ Hansen @ North Carolina State University

* Date: 11/29/21

* From:

* About: Initializes all storage arrays to zero

*

**********************************************************************************************************************************************/

void init_array(){

int i;

for(i=0;i<EPC_COUNT;i++){

EPC_recv[i][0] = 0;

}

}

/************************************************************************************************************************************************

* Function: check_array

* Author: DJ Hansen @ North Carolina State University

* Date: 11/29/21

* From:

* About: Checks to see if the scanned tag has already been scanned in this section

*

**********************************************************************************************************************************************/

bool check_array(uint8_t * msg){

int i,j;

int found;

i=0;

// as long as not end of list

while(i < EPC_COUNT && EPC_recv[i][0] != 0) {

found = 1;

for (j = 0 ; j < 12 ; j++) {

if (EPC_recv[ i ] [ j ] != msg[31 + j]) {

found = 0;

j = 12;

i++;

}

}

// if found

if (found == 1) return 1;

}

return 0;

}

/************************************************************************************************************************************************

* Function: add_array

* Author: DJ Hansen @ North Carolina State University

* Date: 11/29/21

* From:

* About: If this tag has not been scanned this section, then store it

*

**********************************************************************************************************************************************/

void add_array(uint8_t *msg) {

int i,j;

int found;

i=0;

// as long as not end of list

while(i < EPC_COUNT && EPC_recv[i][0] != 0) {

found = 1;

for (j = 0 ; j < 12 ; j++) {

if (EPC_recv[ i ] [ j ] != msg[31 + j]){

found = 0;

j = 12;

i++;

}

}

// if found

if (found == 1) return;

}

if (i == EPC_COUNT) {

Serial.print(F("Can not add more to array"));

Serial.println();

return;

}

// add to array

for (j = 0 ; j < 12 ; j++) {

EPC_recv[ i ] [ j ] = msg[31 + j];

}

Serial.print(F("Entry added"));

Serial.println();

}

/************************************************************************************************************************************************

* Function: count_entries

* Author: DJ Hansen @ North Carolina State University

* Date: 11/29/21

* From:

* About: Counts the number of tags scanned in a session

*

**********************************************************************************************************************************************/

int count_entries() {

int i=0;

while(i < EPC_COUNT) {

if( EPC_recv[ i ] [ 0 ] == 0) break;

i++;

}

return i;

}

/************************************************************************************************************************************************

* Function: clear_arrays

* Author: DJ Hansen @ North Carolina State University

* Date: 11/29/21

* From:

* About: same as init_array only this also sets the tag data sent to the database to a null string

*

**********************************************************************************************************************************************/

void clear_arrays(void){

for(int i = 0; i < EPC_COUNT; i++){

for(int j = 0; j < 12; j++){

EPC_recv[i][j] = 0;

final_epc[i] = "";

}

}

}

DATABASE CODE

/************************************************************************************************************************************************

* Function: database

* Author: DJ Hansen @ North Carolina State University

* Date: 11/29/21

* From:

* About: connects to wifi, converts collected tag data to string, and sends an HTTP request to the apache web server setup using xampp.

*

**********************************************************************************************************************************************/

void database(){

unsigned long curr_time_db = millis();

// setup wifi connection

if(WiFi.status() != WL_CONNECTED){

connect_to_wifi();

}

convert_epc_string();

for(int h = 0; h < count_entries(); h++){

queryString = "?epc=" + final_epc[h];

http.begin(HOST_NAME + PATH_NAME + queryString); //HTTP

httpCode = http.GET();

if(httpCode > 0) { // httpCode will be negative on error

if(httpCode == HTTP_CODE_OK) {

payload = http.getString();

Serial.println(payload);

Serial.println(httpCode);

Serial.println("here");

} else { // HTTP header has been send and Server response header has been handled

Serial.printf("[HTTP] GET... code: %d\n", httpCode);

}

} else {

Serial.printf("[HTTP] GET... failed, error: %s\n", http.errorToString(httpCode).c_str());

}

http.end();

}

clear_arrays_db();

prev_time_db = curr_time_db;

if(!first_flag){

first_flag = 1;

}

}

/************************************************************************************************************************************************

* Function: connect_to_wifi

* Author: DJ Hansen @ North Carolina State University

* Date: 11/29/21

* From:

* About: sets up wifi connection

*

**********************************************************************************************************************************************/

void connect_to_wifi(void){

WiFi.begin(WIFI_SSID, WIFI_PASSWORD);

Serial.println("Connecting");

while(WiFi.status() != WL_CONNECTED) {

delay(500);

Serial.print(".");

}

Serial.println("");

Serial.print("Connected to WiFi network with IP Address: ");

Serial.println(WiFi.localIP());

}

/************************************************************************************************************************************************

* Function: convert_epc_string

* Author: DJ Hansen @ North Carolina State University

* Date: 11/29/21

* From:

* About: simple integer array to string

*

**********************************************************************************************************************************************/

void convert_epc_string(void){

for(int i = 0; i < count_entries(); i++){

for(int j = 0; j < 12; j++){

final_epc[i] += String(EPC_recv[i][j]);

}

}

}

/************************************************************************************************************************************************

* Function: clear_arrays_db

* Author: DJ Hansen @ North Carolina State University

* Date: 11/29/21

* From:

* About: same as clear_arrays

**********************************************************************************************************************************************/

void clear_arrays_db(void){

for(int i = 0; i < EPC_COUNT; i++){

for(int j = 0; j < 12; j++){

EPC_recv[i][j] = 0;

final_epc[i] = "";

}

}

}

IMAGE CODE

Paste the appropriate image_266_296x152_BW.c file converted into hexadecimal format in this file.

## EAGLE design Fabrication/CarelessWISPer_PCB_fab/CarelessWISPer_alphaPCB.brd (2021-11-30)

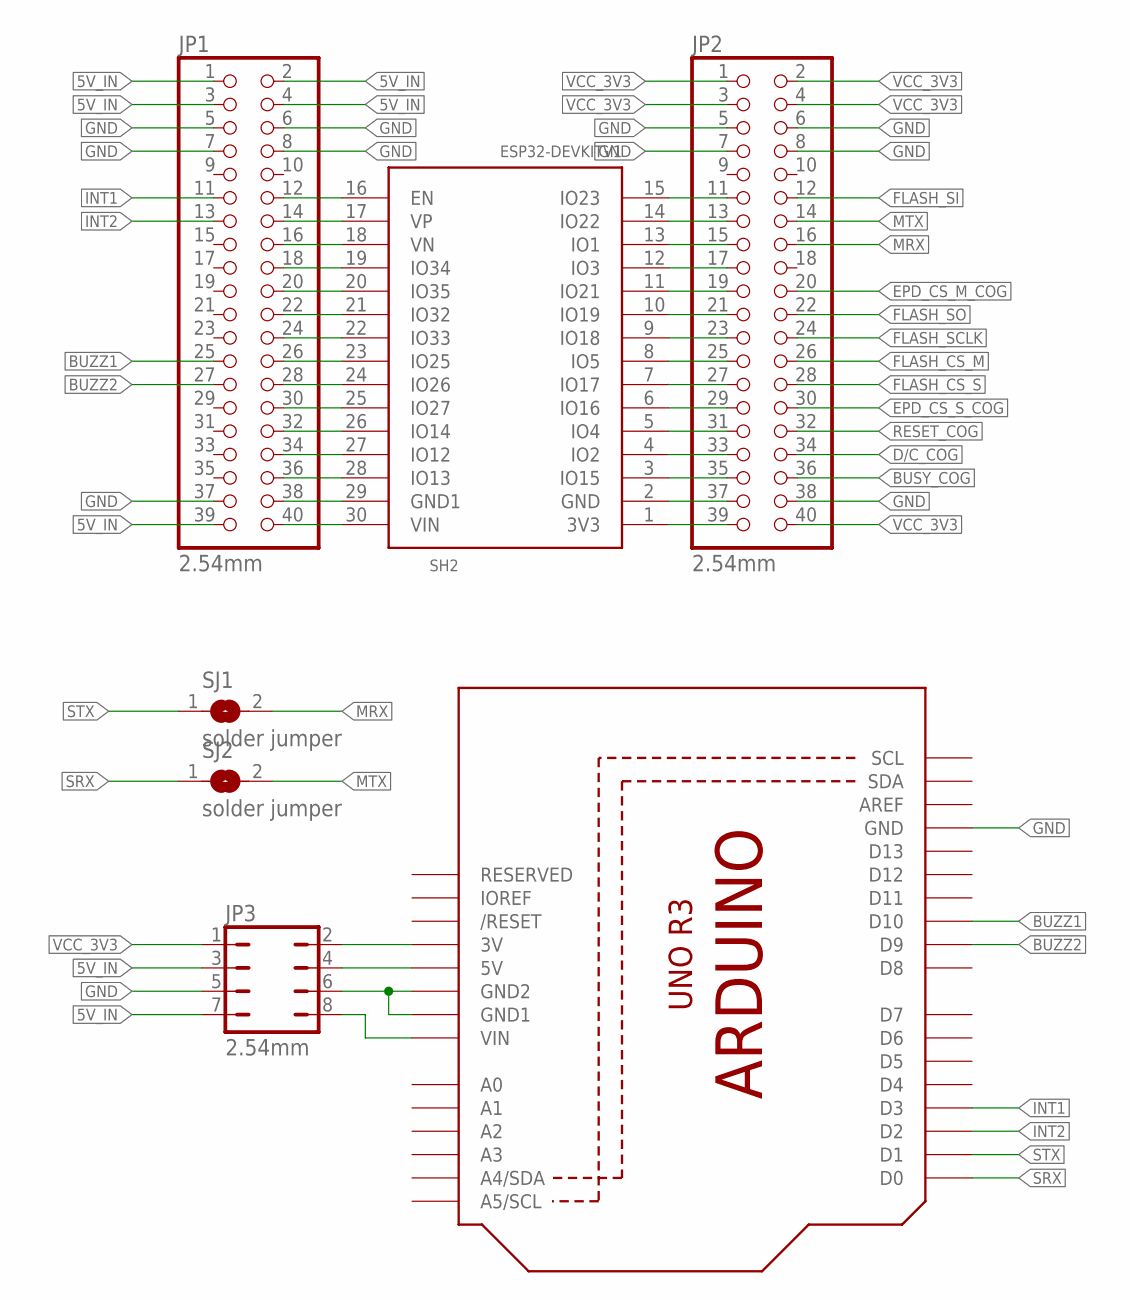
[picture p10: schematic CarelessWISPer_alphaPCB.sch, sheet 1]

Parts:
JP1, JP2: 2.54mm; 2X20
JP3: 2.54mm; JP4Q
SH1: ARDUINOR3-BPLACE
SH2: ESP32-DEVKIT1_FIX; ESP32-DEVKITV1
SJ1, SJ2: solder jumper; SJ

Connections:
3V: JP3.2, SH1.3V
5V: JP3.4, SH1.5V
5V_IN: JP1.1, JP1.2, JP1.3, JP1.4, JP1.39, JP3.3, JP3.7
BUSY_COG: JP2.36; also elsewhere on the board
BUZZ1: JP1.25, SH1.D10
BUZZ2: JP1.27, SH1.D9
D/C_COG: JP2.34; also elsewhere on the board
EPD_CS_M_COG: JP2.20; also elsewhere on the board
EPD_CS_S_COG: JP2.30; also elsewhere on the board
FLASH_CS_M: JP2.26; also elsewhere on the board
FLASH_CS_S: JP2.28; also elsewhere on the board
FLASH_SCLK: JP2.24; also elsewhere on the board
FLASH_SI: JP2.12; also elsewhere on the board
FLASH_SO: JP2.22; also elsewhere on the board
GND: JP1.5, JP1.6, JP1.7, JP1.8, JP1.37, JP2.5, JP2.6, JP2.7, JP2.8, JP2.38, JP3.5, SH1.GND; also elsewhere on the board
GND1: JP1.38, SH2.29 (GND1)
GND2: JP3.6, SH1.GND1, SH1.GND2
INT1: JP1.11, SH1.D3
INT2: JP1.13, SH1.D2
IO1: JP2.15, SH2.13 (IO1)
IO2: JP2.33, SH2.4 (IO2)
IO3: JP2.17, SH2.12 (IO3)
IO3V3: JP2.39, SH2.1 (3V3)
IO4: JP2.31, SH2.5 (IO4)
IO5: JP2.25, SH2.8 (IO5)
IO12: JP1.34, SH2.27 (IO12)
IO13: JP1.36, SH2.28 (IO13)
IO14: JP1.32, SH2.26 (IO14)
IO15: JP2.35, SH2.3 (IO15)
IO16: JP2.29, SH2.6 (IO16)
IO17: JP2.27, SH2.7 (IO17)
IO18: JP2.23, SH2.9 (IO18)
IO19: JP2.21, SH2.10 (IO19)
IO21: JP2.19, SH2.11 (IO21)
IO22: JP2.13, SH2.14 (IO22)
IO23: JP2.11, SH2.15 (IO23)
IO25: JP1.26, SH2.23 (IO25)
IO26: JP1.28, SH2.24 (IO26)
IO27: JP1.30, SH2.25 (IO27)
IO32: JP1.22, SH2.21 (IO32)
IO33: JP1.24, SH2.22 (IO33)
IO34: JP1.18, SH2.19 (IO34)
IO35: JP1.20, SH2.20 (IO35)
IOEN: JP1.12, SH2.16 (EN)
IOGND: JP2.37, SH2.2 (GND)
IOVIN: JP1.40, SH2.30 (VIN)
IOVN: JP1.16, SH2.18 (VN)
IOVP: JP1.14, SH2.17 (VP)
MRX: JP2.16, SJ1.2
MTX: JP2.14, SJ2.2
RESET_COG: JP2.32; also elsewhere on the board
SRX: SH1.D0, SJ2.1
STX: SH1.D1, SJ1.1
VCC_3V3: JP2.1, JP2.2, JP2.3, JP2.4, JP2.40, JP3.1; also elsewhere on the board
VIN: JP3.8, SH1.VIN

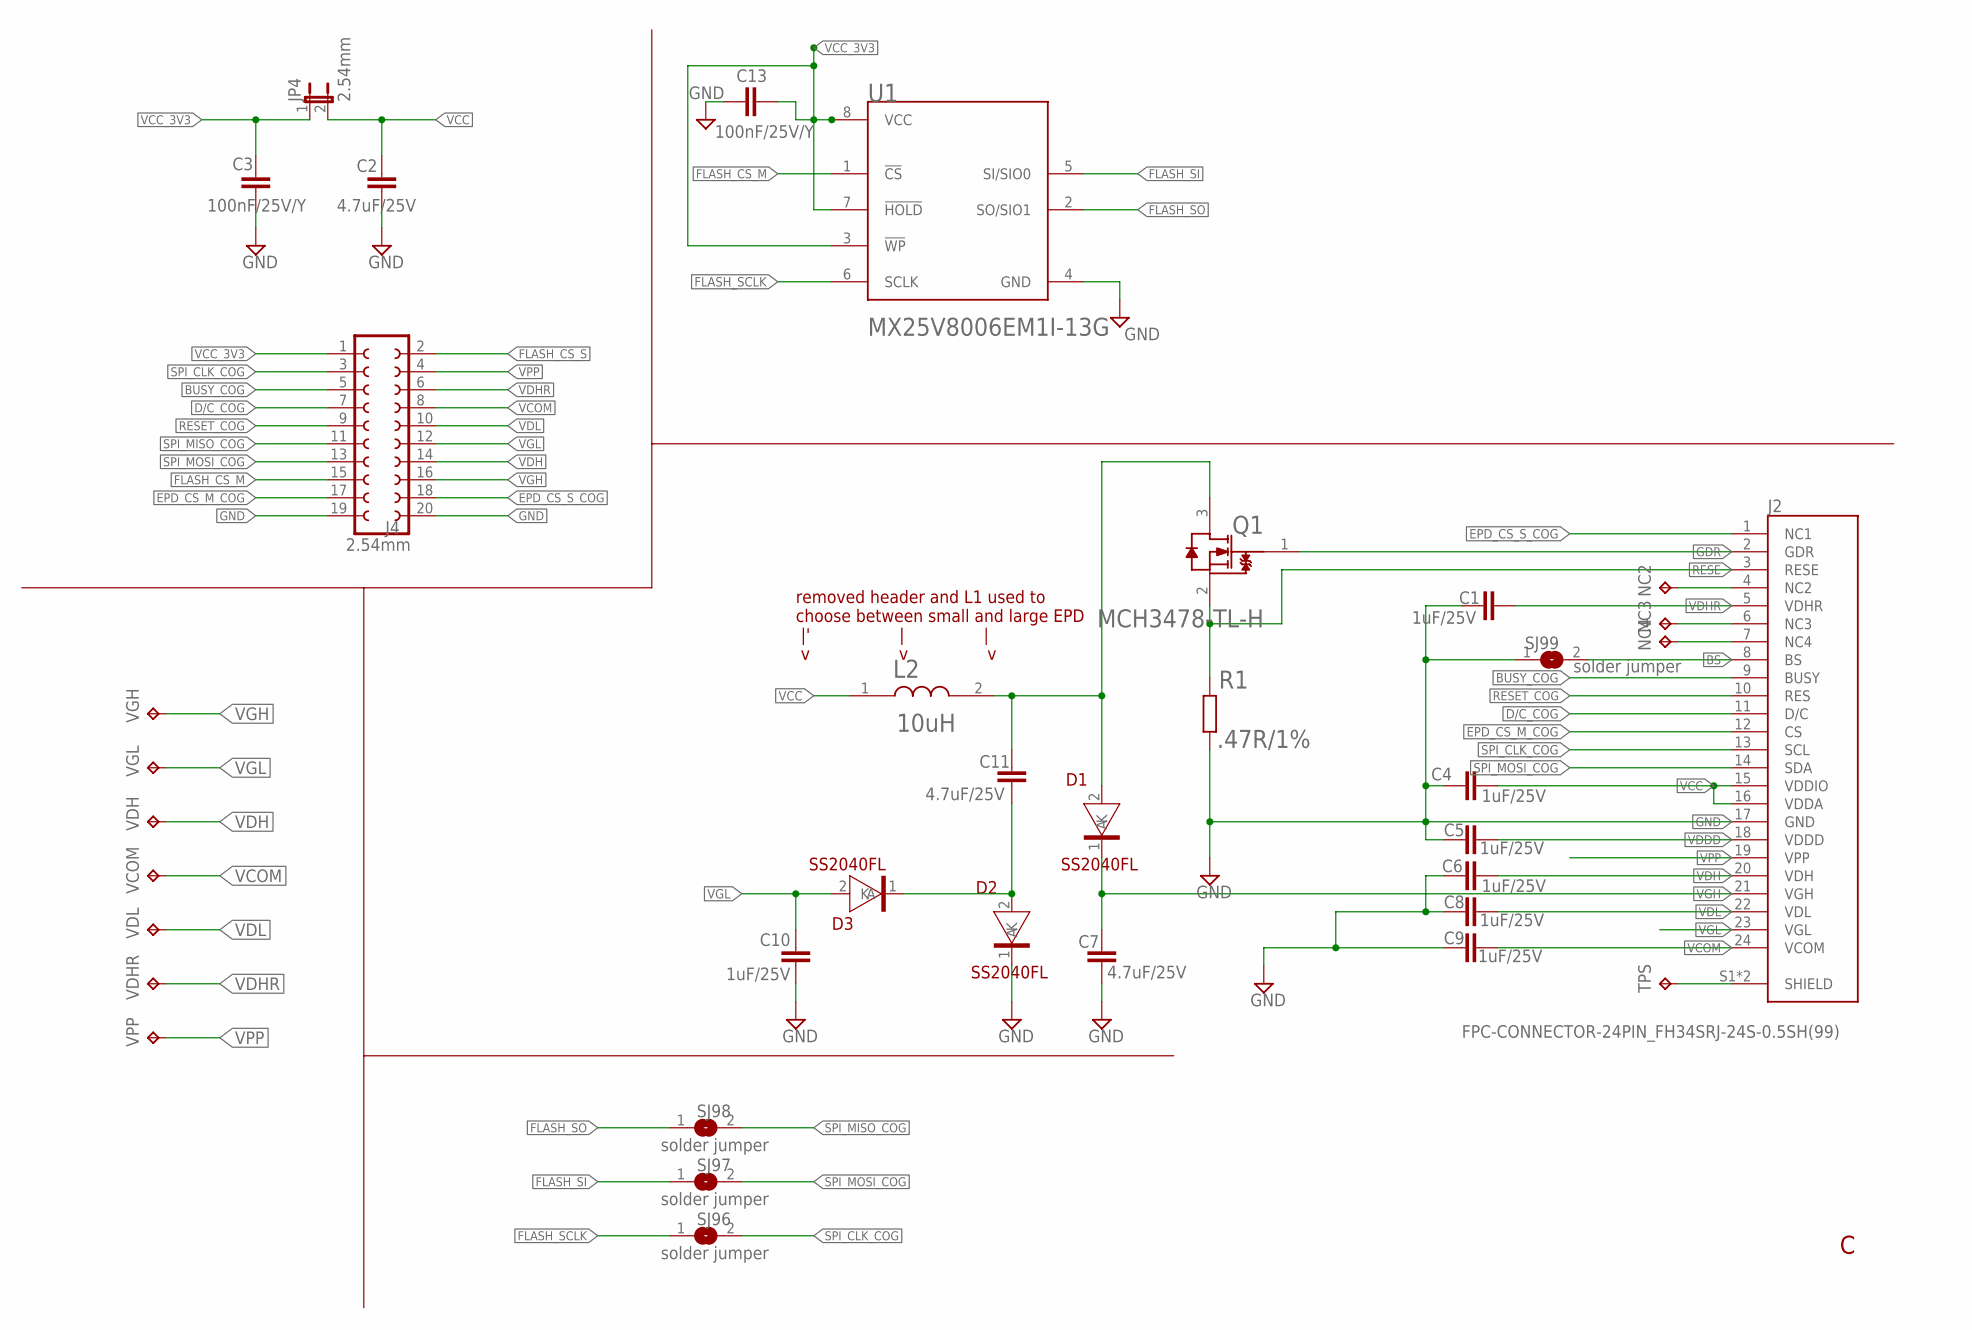
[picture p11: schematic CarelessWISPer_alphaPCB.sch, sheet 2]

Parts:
C1, C4, C5, C6, C8, C9, C10: 1uF/25V; CAPC2012X110
C2, C7, C11: 4.7uF/25V; CAPC2012X110
C3, C13: 100nF/25V/Y; CAPC2012X110
D1, D2, D3: SS2040FL; SOD-123FL
J2: FPC-CONNECTOR-24PIN_FH34SRJ-24S-0.5SH(99); FPC-CONNECTOR-24PIN_HRS_FH34SRJ-24S-0.5SH(99)
J4: 2.54mm; FE10-2W
JP4: 2.54mm; JP1
L2: MURATA_LQH3NPZ100MMELMURATA_LQH3NPZ100MMEL_0_0; MURATA_LQH3NPZ100MMEL_0
NC2, NC3, NC4: TPB1,27; B1,27
Q1: ON_SEMICONDUCTOR_MCH3478-TL-HON_SEMICONDUCTOR_MCH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; ON_SEMICONDUCTOR_MCH3478-TL-H_0
R1: .47R/1%; RESC2012X65
SJ96, SJ97, SJ98, SJ99: solder jumper; SJ
TPS: TPB1,27; B1,27
U1: MACRONIX_MX25V8006EM1I-13GMACRONIX_MX25V8006EM1I-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; MACRONIX_MX25V8006EM1I-13G_0
VCOM: TPB1,27; B1,27
VDH: TPB1,27; B1,27
VDHR: TPB1,27; B1,27
VDL: TPB1,27; B1,27
VGH: TPB1,27; B1,27
VGL: TPB1,27; B1,27
VPP: TPB1,27; B1,27

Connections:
BS: J2.8 (BS), SJ99.2
BUSY_COG: J2.9 (BUSY), J4.5; also elsewhere on the board
D/C_COG: J2.11 (D/C), J4.7; also elsewhere on the board
DIODE_JUNCT: C11.1, D2.2 (A), D3.1 (K)
EPD_CS_M_COG: J2.12 (CS), J4.17; also elsewhere on the board
EPD_CS_S_COG: J2.1 (NC1), J4.18; also elsewhere on the board
FLASH_CS_M: J4.15, U1.1 (!CS!); also elsewhere on the board
FLASH_CS_S: J4.2; also elsewhere on the board
FLASH_SCLK: SJ96.1, U1.6 (SCLK); also elsewhere on the board
FLASH_SI: SJ97.1, U1.5 (SI/SIO0); also elsewhere on the board
FLASH_SO: SJ98.1, U1.2 (SO/SIO1); also elsewhere on the board
GDR: J2.2 (GDR), Q1.1 (G)
GND: C1.1, C2.1, C3.1, C4.2, C5.2, C6.2, C7.1, C8.2, C9.2, C10.2, C13.1, D2.1 (K), J2.17 (GND), J4.19, J4.20, R1.1, SJ99.1, U1.4 (GND); also elsewhere on the board
L2-Q1: C11.2, D1.2 (A), L2.2, Q1.3 (D)
NC1: J2.S1 (SHIELD), J2.S2 (SHIELD), TPS.TP
NC2: J2.4 (NC2), NC2.TP
NC3: J2.6 (NC3), NC3.TP
NC4: J2.7 (NC4), NC4.TP
RESE: J2.3 (RESE), Q1.2 (S), R1.2
RESET_COG: J2.10 (RES), J4.9; also elsewhere on the board
SPI_CLK_COG: J2.13 (SCL), J4.3, SJ96.2
SPI_MISO_COG: J4.11, SJ98.2
SPI_MOSI_COG: J2.14 (SDA), J4.13, SJ97.2
VCC: C2.2, C4.1, J2.15 (VDDIO), J2.16 (VDDA), JP4.2, L2.1
VCC_3V3: C3.2, C13.2, J4.1, JP4.1, U1.3 (!WP!), U1.7 (!HOLD!), U1.8 (VCC); also elsewhere on the board
VCOM: C9.1, J2.24 (VCOM), J4.8, VCOM.TP
VDDD: C5.1, J2.18 (VDDD)
VDH: C6.1, J2.20 (VDH), J4.14, VDH.TP
VDHR: C1.2, J2.5 (VDHR), J4.6, VDHR.TP
VDL: C8.1, J2.22 (VDL), J4.10, VDL.TP
VGH: C7.2, D1.1 (K), J2.21 (VGH), J4.16, VGH.TP
VGL: C10.1, D3.2 (A), J2.23 (VGL), J4.12, VGL.TP
VPP: J2.19 (VPP), J4.4, VPP.TP

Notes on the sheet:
removed header and L1 used to choose between small and large EPD |' | | v v v

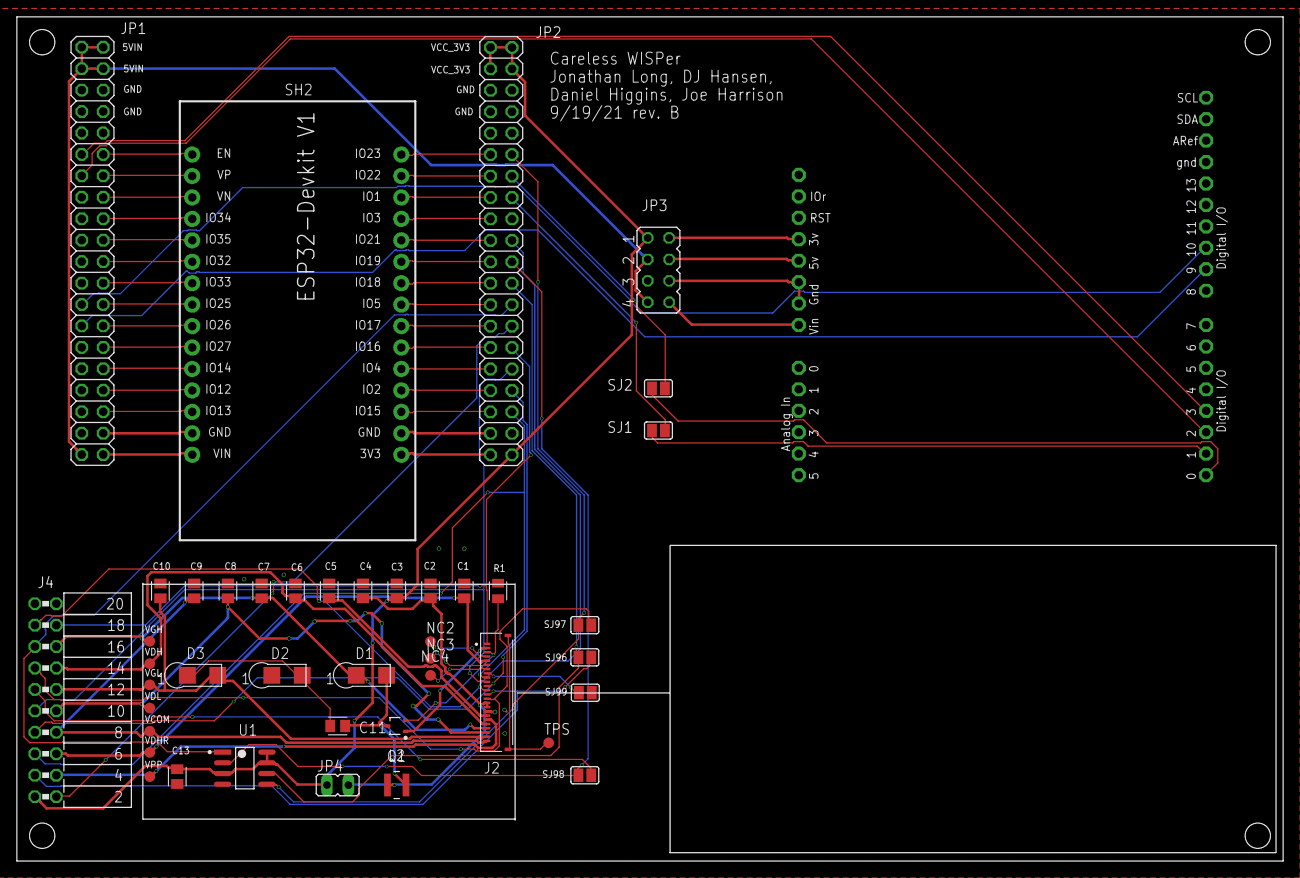
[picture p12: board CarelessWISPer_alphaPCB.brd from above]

Board: 2 copper layers, 150.0 x 100.0 mm, 44 parts (0 on the bottom side), 76 nets.
